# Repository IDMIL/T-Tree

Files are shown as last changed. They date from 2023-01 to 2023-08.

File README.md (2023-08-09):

# T-Tree
## An interactive music system developed at [IDMIL](http://www-new.idmil.org/project/t-tree/)
The T-Tree 1.0 with four T-Sticks

For more information, please check out our [Wiki](https://github.com/IDMIL/T-Tree/wiki)!

## Note
This code is for use with the T-Tree 2.0, which contains a faceplate and an external user interface.
If you are using the T-Tree 1.0, you can still use `led_osc.py` and our performance patches, but `ttree.py` will not work, as it assumes that you have a user interface available.

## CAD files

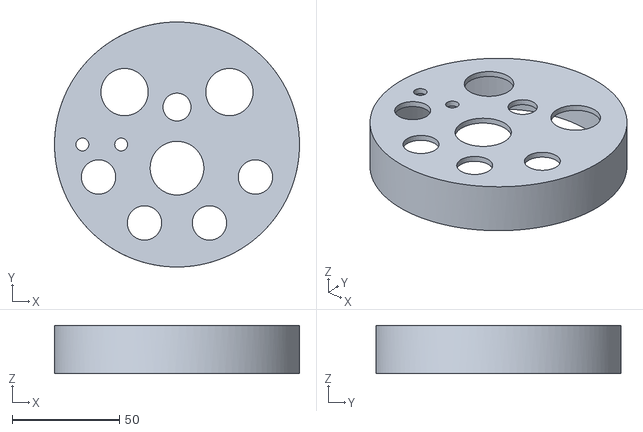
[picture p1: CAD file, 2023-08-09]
assets/T-Tree_2.0_Endcap.stl
114.0 x 114.0 x 22.5

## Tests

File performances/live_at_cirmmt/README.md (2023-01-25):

# live@CIRMMT
## Improvising New Winds

This patch was used in concert on December 9, 2022 for the [Improvising New Winds](https://www.cirmmt.org/en/events/live-cirmmt/improvising-new-winds) concert, part of the live@CIRMMT concert series.

There were three performers, [Paul Buser](https://github.com/p42ul), [Kasey Pocius](https://github.com/kaseypocius), and [Linnea Kirby](https://github.com/linneakirby).

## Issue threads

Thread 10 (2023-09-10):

Preserve state on T-Tree 2.0

p42ul, 2023-09-10:
When T-Sticks are connected to the T-Tree 2.0 and the T-Tree is powered off, it doesn't remember what state it was in and the T-Sticks need to be paired again.

Preserving state between reboots or if the process crashes would be a better user experience.

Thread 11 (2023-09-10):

Redesign structure

p42ul, 2023-09-10:
The T-Tree 2.0 changed some physical aspects of the T-Tree 1.0. One of these changes was moving the Brain to the top of the tree, which had the unintended result of needing cables to be run up to the top. This can create strain on the cables and also looks bad.

For the next design (T-Tree 3.0?) we should reconsider where the Brain should be.

The smaller PVC diameter of the branches also leaves no wiggle room, which can create strain on the T-Sticks themselves. I think going back to the 3" PVC design for the branches would be a good way to go.

p42ul, 2023-09-18:
Related: #5

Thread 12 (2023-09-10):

Make firmware switchable between 1.0 and 2.0

p42ul, 2023-09-10:
The T-Tree firmware currently supports only the T-Tree 2.0. Adding a command-line flag or way to switch between 1.0 and 2.0 would make it more backwards-compatible.

The main difference is that the T-Tree 1.0 doesn't have the external user interface, so is a strict subset of functionality of the T-Tree 2.0.

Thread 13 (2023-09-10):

Document how to create and patches to the T-Tree 2.0

p42ul, 2023-09-10:
In order to use Pure Data patches with the T-Tree 2.0, they need to follow a certain signal flow and be put in the specific `patches/` directory.

Writing documentation about this process would make patch creation more accessible.

p42ul, 2023-09-18:
Currently two ways to upload patches:
1. Use `scp`
2. Pull out microSD card and put them in a particular directory

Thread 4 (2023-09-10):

Make PCB for components

p42ul, 2023-09-10:
There's a [schematic](https://github.com/IDMIL/T-Tree/wiki/Constructing-The-T%E2%80%90Tree#circuit-diagram) for the electronics in the T-Tree 2.0, but a PCB design would simplify the construction process. Currently, all components need to be laid out and soldered by hand.

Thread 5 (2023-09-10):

Improve cable management in Brain

p42ul, 2023-09-10:
The components in the Brain of the T-Tree 2.0 don't have any sort of cable management, and it can get crowded in there. Some kind of cable management solution or way of attaching/organizing the components would make it easier to maintain and swap out different components.

p42ul, 2023-09-18:
#4 would help out with this a lot

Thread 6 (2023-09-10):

Issues with running wired T-Sticks alongside wireless

p42ul, 2023-09-10:
The T-Tree binary sometimes raises an exception when running wired T-Sticks along with wireless. More work is needed to investigate why this is.

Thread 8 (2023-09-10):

Unify power supplies

p42ul, 2023-09-10:
Currently, two different power supplies are used: a USB-C connector for the Raspberry Pi, and a DC barrel jack for the LEDs. I tried unifying the power supplies by supplying power via the 5V rail on the Raspberry Pi, but it would reboot for seemingly no reason.

Maybe there's a better way to do this!

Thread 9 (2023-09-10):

Simplify installation

p42ul, 2023-09-10:
Currently, the T-Tree software needs to be installed on top of [Puara](https://github.com/Puara), and although we have `systemd` units for this, the setup process is very manual.

Creating a ready-to-go image for the T-Tree could be a good way to simplify the installation. Or create an install script that handles everything for you.

p42ul, 2023-09-18:
From lightest to heaviest, some potential ways to do this:

1. Create script that automates T-Tree software install on top of a clean Puara install
2. Create fork of Puara that installs T-Tree software and enables I2C, GPIO, etc. (Maybe upstream this back to Puara image?)
3. Create image of T-Tree software based on custom Linux installation like DietPi, Yocto, Buildroot, Ubuntu IOT, etc.

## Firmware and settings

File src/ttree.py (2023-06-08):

# Standard libraries
from dataclasses import dataclass
from functools import partial
from glob import glob
from string import Template
from time import sleep
from typing import Optional
import logging
import shlex
import subprocess

# Local libraries
from buttons import ArcadeButton, TTree_Buttons
from puara_serial_manager import puara_serial_manager as psm

STARTING_PORT = 8000
NUM_BRANCHES = 4

PATCH_DIR = '/home/paul/T-Tree/patches'

PD_INVOCATION = Template('pd -nogui -send "port ${port}" -send "name ${name}" -send "pd dsp 1" -open "${patch}"')
# PD_INVOCATION = Template('osc-utility s --port ${port}')

logging.basicConfig()
logging.getLogger().setLevel(logging.DEBUG)


@dataclass
class Branch:
    port: int
    paired_to: Optional[str]
    patch_index: int
    arcade: ArcadeButton
    patch_proc: Optional[subprocess.Popen]

class TTree:
    def __init__(self):
        self.branches = self.create_branches()
        self.patches = self.find_patches()
        self.setup_buttons()

    def setup_buttons(self):
        for i, branch in enumerate(self.branches):
            branch.arcade.button.when_pressed = partial(self.change_patch, i)

    def create_branches(self, num_branches=NUM_BRANCHES, starting_port=STARTING_PORT):
        return tuple(Branch(port=starting_port+i,
                            paired_to=None,
                            patch_index=-1,
                            arcade=TTree_Buttons[i],
                            patch_proc=None) for i in range(num_branches))

    def find_patches(self):
        return glob(f'{PATCH_DIR}/*.pd')

    def launch_pd(self, port, name, patch):
        invocation = PD_INVOCATION.substitute(port=port, name=name, patch=patch)
        logging.debug(f'running {invocation}')
        invocation = shlex.split(invocation)
        print(invocation)
        # return subprocess.Popen(invocation, stdout=subprocess.PIPE)
        return subprocess.Popen(invocation, stderr=subprocess.DEVNULL, stdout=subprocess.DEVNULL)

    def change_patch(self, branch_index):
        branch = self.branches[branch_index]
        if not branch.paired_to:
            return
        logging.debug(f'changing patch for {branch.arcade.color}')
        if branch.patch_proc:
            branch.patch_proc.kill()
        branch.patch_index = (branch.patch_index + 1) % len(self.patches)
        branch.patch_proc = self.launch_pd(branch.port, branch.paired_to, self.patches[branch.patch_index])

    def pair(self, branch_index, device_name):
        branch = self.branches[branch_index]
        branch.paired_to = device_name
        branch.patch_index = 0
        if branch.patch_proc:
            branch.patch_proc.kill()
        branch.patch_proc = self.launch_pd(branch.port, device_name, self.patches[0])
        branch.arcade.led.on()

    def config_delegate(self, device_name) -> psm.Config:
        logging.debug('pairing...')
        for branch in self.branches:
            branch.arcade.led.blink()
        while sum(b.arcade.button.value for b in self.branches) <= 0:
            pass
        pressed_index = 0
        for branch in self.branches:
            branch.arcade.led.off()
        for i in range(len(self.branches)):
            if self.branches[i].arcade.button.value == 1:
                pressed_index = i
                break
        self.pair(pressed_index, device_name)
        return psm.Config('192.168.90.1', self.branches[pressed_index].port)


if __name__ == '__main__':
    ttree = TTree()
    sm = psm.SerialManager(wifi=psm.WifiNetwork('2tree', 'mappings'), config_delegate=ttree.config_delegate)
    while True:
        sleep(1)

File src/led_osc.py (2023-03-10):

"""T-Tree LED OSC Server.
Usage:
  led_osc.py [--fake] (spi|pwm)
  led_osc.py -h | --help
  led_osc.py -v | --version
Options:
  --fake        Print the LED status rather than outputting to GPIO.
  -h --help     Show this screen.
  -v --version  Show version.
"""
# Standard library
from time import sleep
import threading

# Third-party libraries
from colour import Color
from docopt import docopt
from pythonosc.dispatcher import Dispatcher
from pythonosc.osc_server import BlockingOSCUDPServer

# Local libraries
from led_ring import LEDRing, RealLED, FakeLED

IP = '0.0.0.0'
PORT = 1234

class OscLed:
    def __init__(self, ring: LEDRing):
        self.ring = ring
        server = self._create_osc_server()
        threading.Thread(target=server.serve_forever, daemon=True).start()

    def _create_osc_server(self):
        dispatcher = Dispatcher()
        dispatcher.map('/led_ring/set_ring/*', self.led_ring_handler)
        dispatcher.map('/led_ring/set_led/*/*', self.individual_led_handler)
        return BlockingOSCUDPServer((IP, PORT), dispatcher)

    def individual_led_handler(self, address, *args):
        address = address.split('/')
        try:
            led_num = int(address[-1])
            if led_num < 0 or led_num >= self.ring.leds_per_ring:
                raise ValueError
        except ValueError:
            print(f'address of led must be an int between 0 and {self.ring.leds_per_ring-1}. received: {address[-1]}')
            return
        try:
            ring_num = int(address[-2])
            if ring_num < 0 or ring_num >= self.ring.num_rings:
                raise ValueError
        except ValueError:
            print(f'address of ring must be an int between 0 and {self.ring.num_rings-1}. received: {address[-2]}')
            return
        if len(args) != 3:
            print(f'this handler requires 3 float values (r, g, b). received: {args}')
            return
        for i in range(len(args)):
            if type(args[i]) is not float or args[i] < 0.0 or args[i] > 1.0:
                print(f'(r, g, b) values must all be floats in [0, 1]. received {args}')
                return
        c = Color()
        c.set_rgb(args)
        self.ring.set_led(ring_num, led_num, c)

    def led_ring_handler(self, address, *args):
        address = address.split('/')
        try:
            ring_num = int(address[-1])
            if ring_num < 0 or ring_num >= self.ring.num_rings:
                raise ValueError
        except ValueError:
            print(f'address of ring must be an int between 0 and {self.ring.num_rings}. received: {address[-1]}')
            return
        if len(args) != 3:
            print(f'this handler requires 3 float values (r, g, b). received: {args}')
            return
        for i in range(len(args)):
            if type(args[i]) is not float or args[i] < 0.0 or args[i] > 1.0:
                print(f'(r, g, b) values must all be floats in [0, 1]. received {args}')
                return
        c = Color()
        c.set_rgb(args)
        self.ring.set_ring(ring_num, c)


def main(args):
    method = None
    if args['spi']:
        method = 'spi'
    elif args['pwm']:
        method = 'pwm'


    if args['--fake']:
        osc_led = OscLed(FakeLED())
    else:
        try:
            osc_led = OscLed(RealLED(method=method))
        except NotImplementedError as e:
            print(e)
            print("If you're not running on a Raspberry Pi, try using the --fake option.")
            return
    print(f'Running OSC server at {IP}:{PORT}. Press Ctrl+C to quit.')
    while True:
        sleep(1)

if __name__ == '__main__':
    args = docopt(__doc__, version="T-Tree LED OSC Server 0.1")
    main(args)

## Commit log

2022-09-25 Clean up and put main code in a thread.
2022-09-25 Clean up and put main code in a thread.
    Former-commit-id: f1f7b2247d498b2b4bf58e1dd734ae80d7ed375f
2022-09-27 Remove unused commands. Make Settings and Config buttons wori.
2022-09-27 Remove unused commands. Make Settings and Config buttons wori.
    Former-commit-id: 392a49ae450ee0ccd8c04be495706c722bcf34ce
2022-10-12 Match Puara framework's serial communication protocol.
2022-10-12 Match Puara framework's serial communication protocol.
    Former-commit-id: e7b544485e07b2dc27894304e214dcf45c923f8d
2022-11-03 Add calibrator for finding signal min and max.
2022-11-03 Add calibrator for finding signal min and max.
    Former-commit-id: 07f324eb62cb243066e56aa855567c0b0f2ad0a2
2022-11-14 Add systemd service file for LED code
2022-11-14 Add systemd service file for LED code
    Former-commit-id: 95375b5fb3cb62971fb41b89493dc2966402a0dc
2022-11-15 Move calibrator.py from https://github.com/Puara/puara-client
2022-11-15 Move calibrator.py from https://github.com/Puara/puara-client
    Former-commit-id: f2438e99e7c3028b8e7e2e81f44768178cc79343
2022-11-15 Genericize calibrator.py
2022-11-15 Genericize calibrator.py
    Former-commit-id: 220e7e4a13593f8e704458303a2e94bfb8e797d2
2022-11-15 Remove unused method from calibrator
2022-11-15 Remove unused method from calibrator
    Former-commit-id: 36a4834b326a93bdaa58f2ede341573099c3da34
2022-11-22 Add code for setting individual LEDs
2022-11-22 Add code for setting individual LEDs
    Former-commit-id: 68397c594d032758ed6335d463a6b1fd6ed7ed18
2022-11-22 Fix RealLED def->class
    Former-commit-id: b78f63bc955d51a456169adbda588f7eb2e66b5f
    [led_ring.py]
2022-11-22 Add LED LFO tester in VCV Rack
2022-11-22 Add LED LFO tester in VCV Rack
    Former-commit-id: 453628dbe0476f2fdfcd6b5a9ae726bcdee3ec7c
2022-11-30 Add off tool and use real LEDs
2022-11-30 Add off tool and use real LEDs
    Former-commit-id: 983e7ca58324657ad20e64dd164ca80a22c85668
2022-11-30 Add led_off.py
2022-11-30 Add led_off.py
    Former-commit-id: 5348f1967cade23bed03be819455c9e6252aced9
2022-11-30 Fix RGB code for pixels. Fix error messages
    [led_osc.py, led_ring.py]
2022-11-30 Fix RGB code for pixels. Fix error messages
    Former-commit-id: 1e883be9c35066a0c491b5ea7c1f7ae64c987ea3
    [led_osc.py, led_ring.py]
2022-11-30 fix leds
2022-11-30 fix leds
    Former-commit-id: 9db75e1d67dcbf9074fe7f9abdb71f5deeb5368b
2022-12-01 add t-stick LED interaction
    add t-stick LED interaction, optimize SPAT Json to have MMR model, Minor Tweaks to VCV patch
2022-12-01 add t-stick LED interaction
    Former-commit-id: ecc61355ccacd2a72011036e89987a6b9b8e2e44
    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
2022-12-06 Add commandline option to run with fake LEDs.
2022-12-06 Add commandline option to run with fake LEDs.
    Former-commit-id: 88160f2e8bcaca1ad164bc30bc2e66b8a4d80886
2023-03-08 Add SPI support.
2023-03-08 Add SPI support.
    Former-commit-id: 88f515a9a2d07bed1b49ff94c747e08c5a850e1e
2023-03-23 Add support for different wired T-Stick firmwares.
2023-05-09 Add support for T-Tree 2.0 buttons.
    Former-commit-id: d999695be46bcdb0da7e3f32f20dce9e86bf45a1
2023-05-10 Add SPI library to requirements.txt
2023-05-25 Move LED senders to utils/
2023-05-25 Add some boilerplate to ttree.py Move led_testing.py to utils/
2023-05-25 Update TTree script.
    Split buttons.py into util and library versions.
2023-06-06 Add new LED functionality
2023-06-08 Move wired T-Stick code to PSM.
2023-08-09 Add endcap STL file
    [T-Tree_2.0_Endcap.stl]
2023-08-09 Reorganize directory structure.
    [T-Tree_2.0_Endcap.stl]
2026-04-04 Add Fritzing circuit diagram
    [2Tree_Brain.fzz]
2026-04-05 Add BOM
2026-04-05 Delete assets/2Tree_Brain_bom.html
    BOM is listed in the wiki
